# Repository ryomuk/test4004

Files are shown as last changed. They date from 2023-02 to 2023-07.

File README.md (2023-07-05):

# test4004
Test system for Intel MCS-4 (4004)  micro computer set

This document is written mostly in Japanese.
If necessary, please use a translation service such as DeepL (I recommend this) or Google.

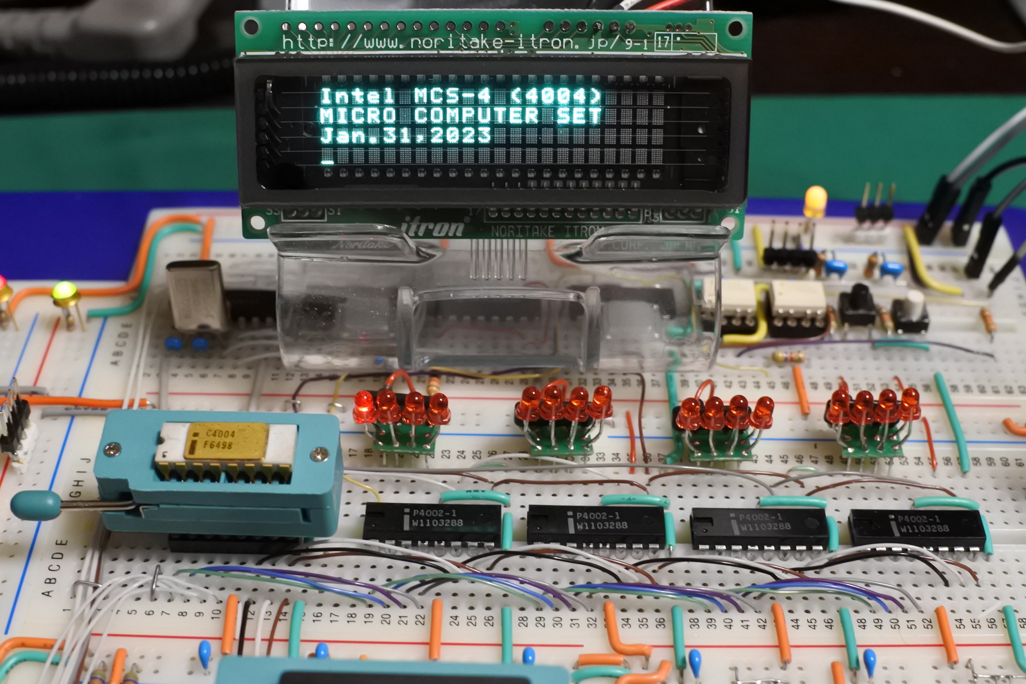
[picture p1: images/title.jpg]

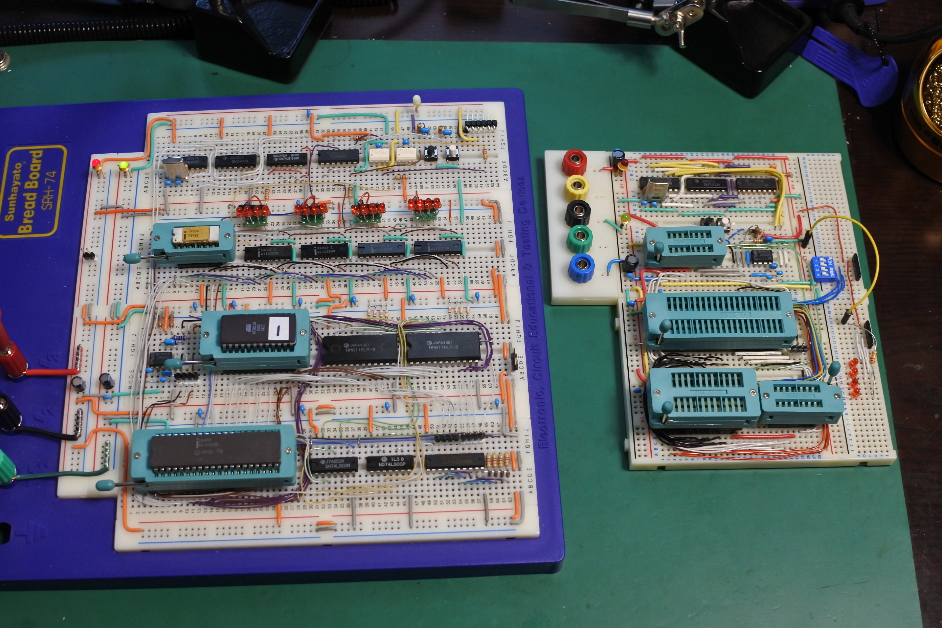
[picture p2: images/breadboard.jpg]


## 概要
昨年，運良くIntel 4004を入手することができました．せっかくだから動かしてみようと思い，このプロジェクトを始めました．
このレポジトリ(test4004)は電卓を作ったところまでで完成．続きはメモリ関連のハードウェアの変更も伴うので別レポジトリ(https://github.com/ryomuk/VTL4004 )に移行します．

## これまでに作ったもの
- 4004実験用ボード
  - シリアル通信用インターフェース
  - 簡易モニター
  - 電卓
  - [VTLインタプリタ(VTL4004)](https://github.com/ryomuk/VTL4004)

## 実験用ボードの仕様
- CPU: Intel 4004
- Clock: 740kHz
- DATA RAM: 4002-1(320bit) x 4
- Program Memory
  - ROM: AT28C64B (8k x 8bit EEPROM)
    - 000H〜EFFHの3.75KB利用可能
  - RAM: HM6268(4k x 4bit SRAM)x 2個
    - F00H〜FFDHの254byte x 16バンク, 合計約4KB
- 通信ポート: 9600bps Software Serial UART (TTL level)

## ToDO
- VTL的な言語
  - マンデルブロ集合を表示するぐらいのプログラムを実行させたい
  - →作りました．( https://github.com/ryomuk/VTL4004 )
- プリント基板作成
  - →作りました．( https://github.com/ryomuk/emu8080on4004 )

## 動画
Youtubeで関連動画を公開しています．
- https://www.youtube.com/@ryomukai/videos

## ブログ
関連する情報が書いてあるかも．
- https://blog.goo.ne.jp/tk-80

## 参考にした文献，サイト
### 4004関連開発事例
- [Intel 4004  50th Anniversary Project](https://www.4004.com/)
  - https://www.4004.com/busicom-replica.html
  - http://www.4004.com/2009/Busicom-141PF-Calculator_asm_rel-1-0-1.txt
- https://github.com/jim11662418/4004-SBC
- https://www.cpushack.com/mcs-4-test-boards-for-sale
- https://github.com/novi/4004MainBoard

### データシート
- http://www.bitsavers.org/components/intel/
- https://www.intel-vintage.info/intelmcs.htm

### 開発環境
- [The Macroassembler AS](http://john.ccac.rwth-aachen.de:8000/as/)
- [Intel 4004 emulator assembler disassembler](http://e4004.szyc.org/)

## 更新履歴
- 2023/2/20: ハードウェアをrev.0.2に更新
  - プログラム領域のメモリ(6116)のA8〜A10を4002のポートに接続してバンク切り替えで256byte(正確には254byte) x 8 バンク使えるようにした．
  -  これに伴い，バンク窓以外の空間をROM用に使う余地がある．
  - モニタプログラムにバンク切り替え命令('B')を追加．
  - rev.0.1は，「CM0とCM1に4002-1を2づつ」という構成でしたが，「CM0に4002-1を2つと4002-2を2つ」という構成も可能にしました．ピンヘッダでCMのラインを切り替えます．
- 2023/2/21: PM_READ_P0_P2 を PM_READ_P0_P1 に変更．
- 2023/2/23: 上記にバグがあったので修正．CTOI_P1_R5をCTOI_P1に変更．
- 2023/2/24: ハードウェアをrev.1.0に更新
  - プログラム領域のROMを2716から28C64B(2764等も可)に変更．
    - 000H〜7FFHだったROM領域を000H〜EFFHに拡大
  - プログラム領域のRAMを6116から6268(たぶん6168でも可)に変更
    - 254byte x 16 バンク使えるようにした．
  - 通信ポートをRAM3に，PMのRAMバンク指定用のポートをRAM0に変更
- 2023/3/12:
  - RAM2, RAM3を4002-1から4002-2に変更
    - RAM2, RAM3のバンク(CMRAM)の設定を1から0に変更
  - CR，LFが入力されたときの挙動の変更．(CRを無視していたのをCR or LFでの入力にした．)
- 2023/4/14: 0100H前後のメモリが重複してSQRTの計算時に暴走してしまっていたので修正
- 2023/7/5: 回路図で6268のピン番号の一部に誤りがあったので修正．(rev1.0→1.01)

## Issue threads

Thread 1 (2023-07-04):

1.0 "Calc" code and Schematic?

slobdir, 2023-07-04:
This was a very interesting project. I wire wrapped something like your Version 1.0 board and I found a few errors in the 1.0 schematic around the 6268. the I/O's should be 1-4: 15,14,13,12 and the /WE_OPx should be pin 11. Are these the only issues?

Also, I could not get SQR or D to work in the CALC.ASM code. Was there an update to the code, this may have been mentioned in your blog? Thanks!

ryomuk, 2023-07-05:
Thanks for your interest and the error report.
I have corrected the schematic and updated to rev.1.01.
As for the CALC.ASM, previously I found a bug and uploaded the fixed version on Apr.14. I recompiled it and run on the board. It works fine and I found no errors.
I am using 4002-2 (not 4002-1) for RAM2 and RAM3, but it should not matter.

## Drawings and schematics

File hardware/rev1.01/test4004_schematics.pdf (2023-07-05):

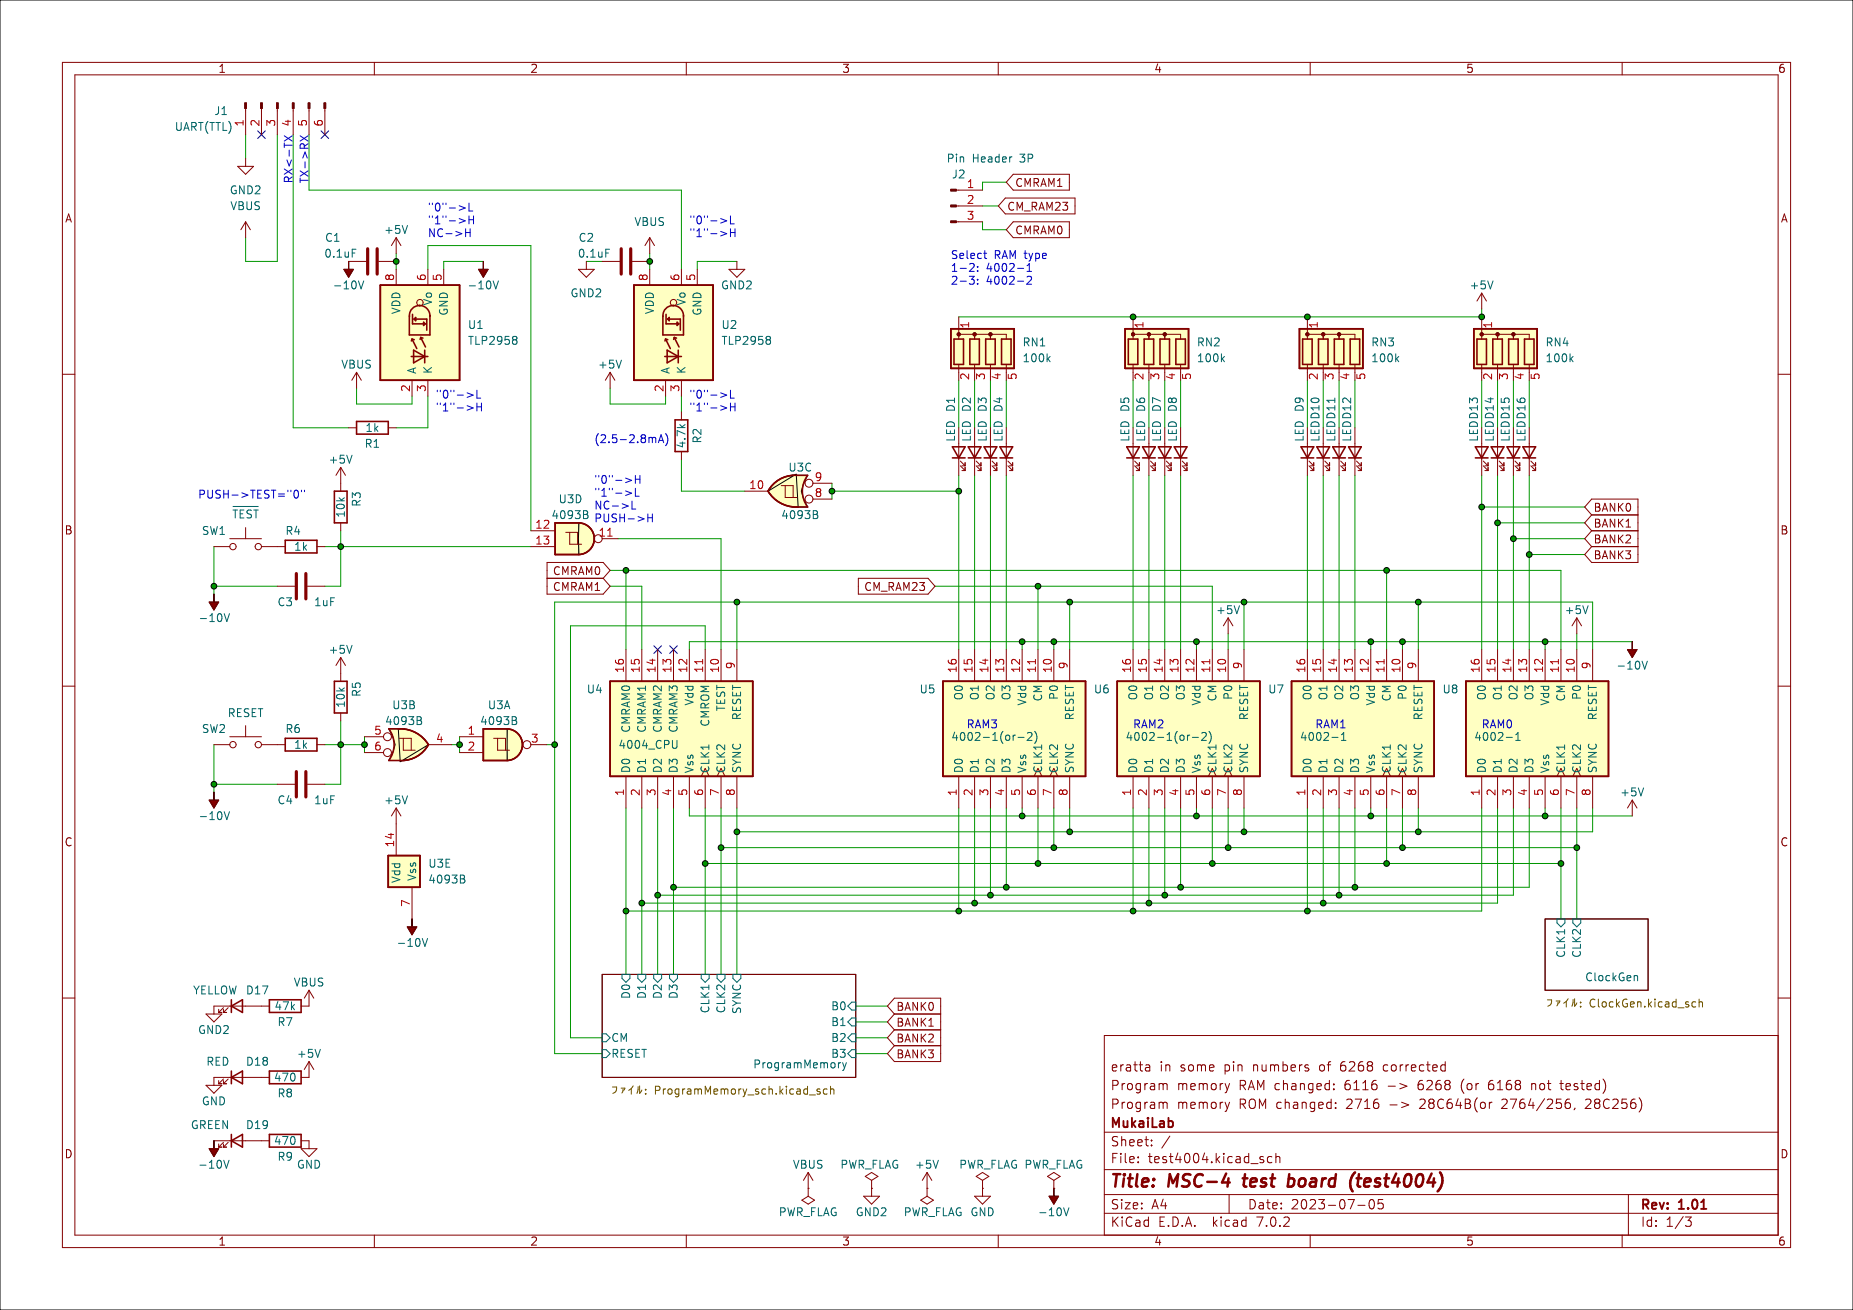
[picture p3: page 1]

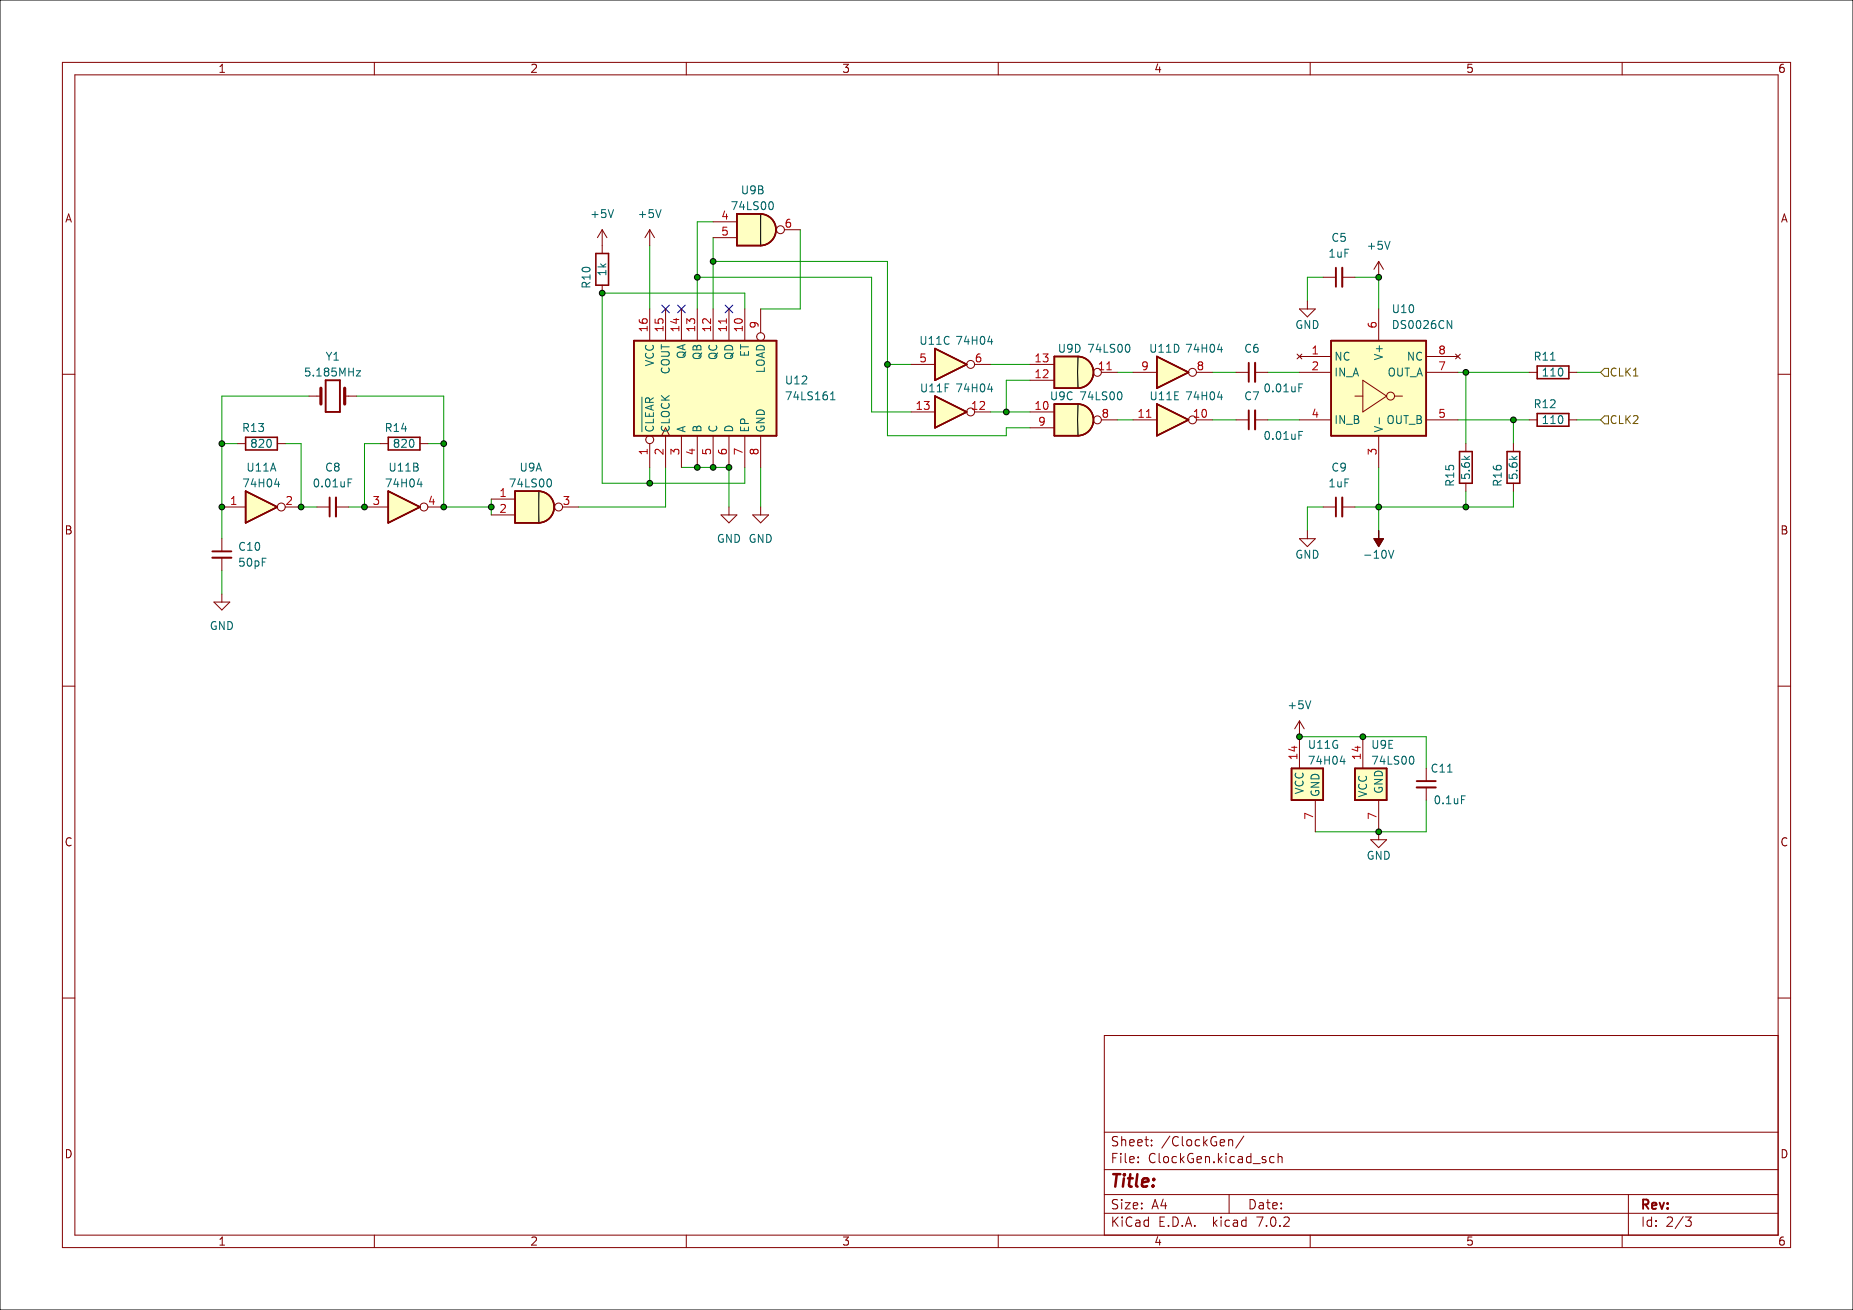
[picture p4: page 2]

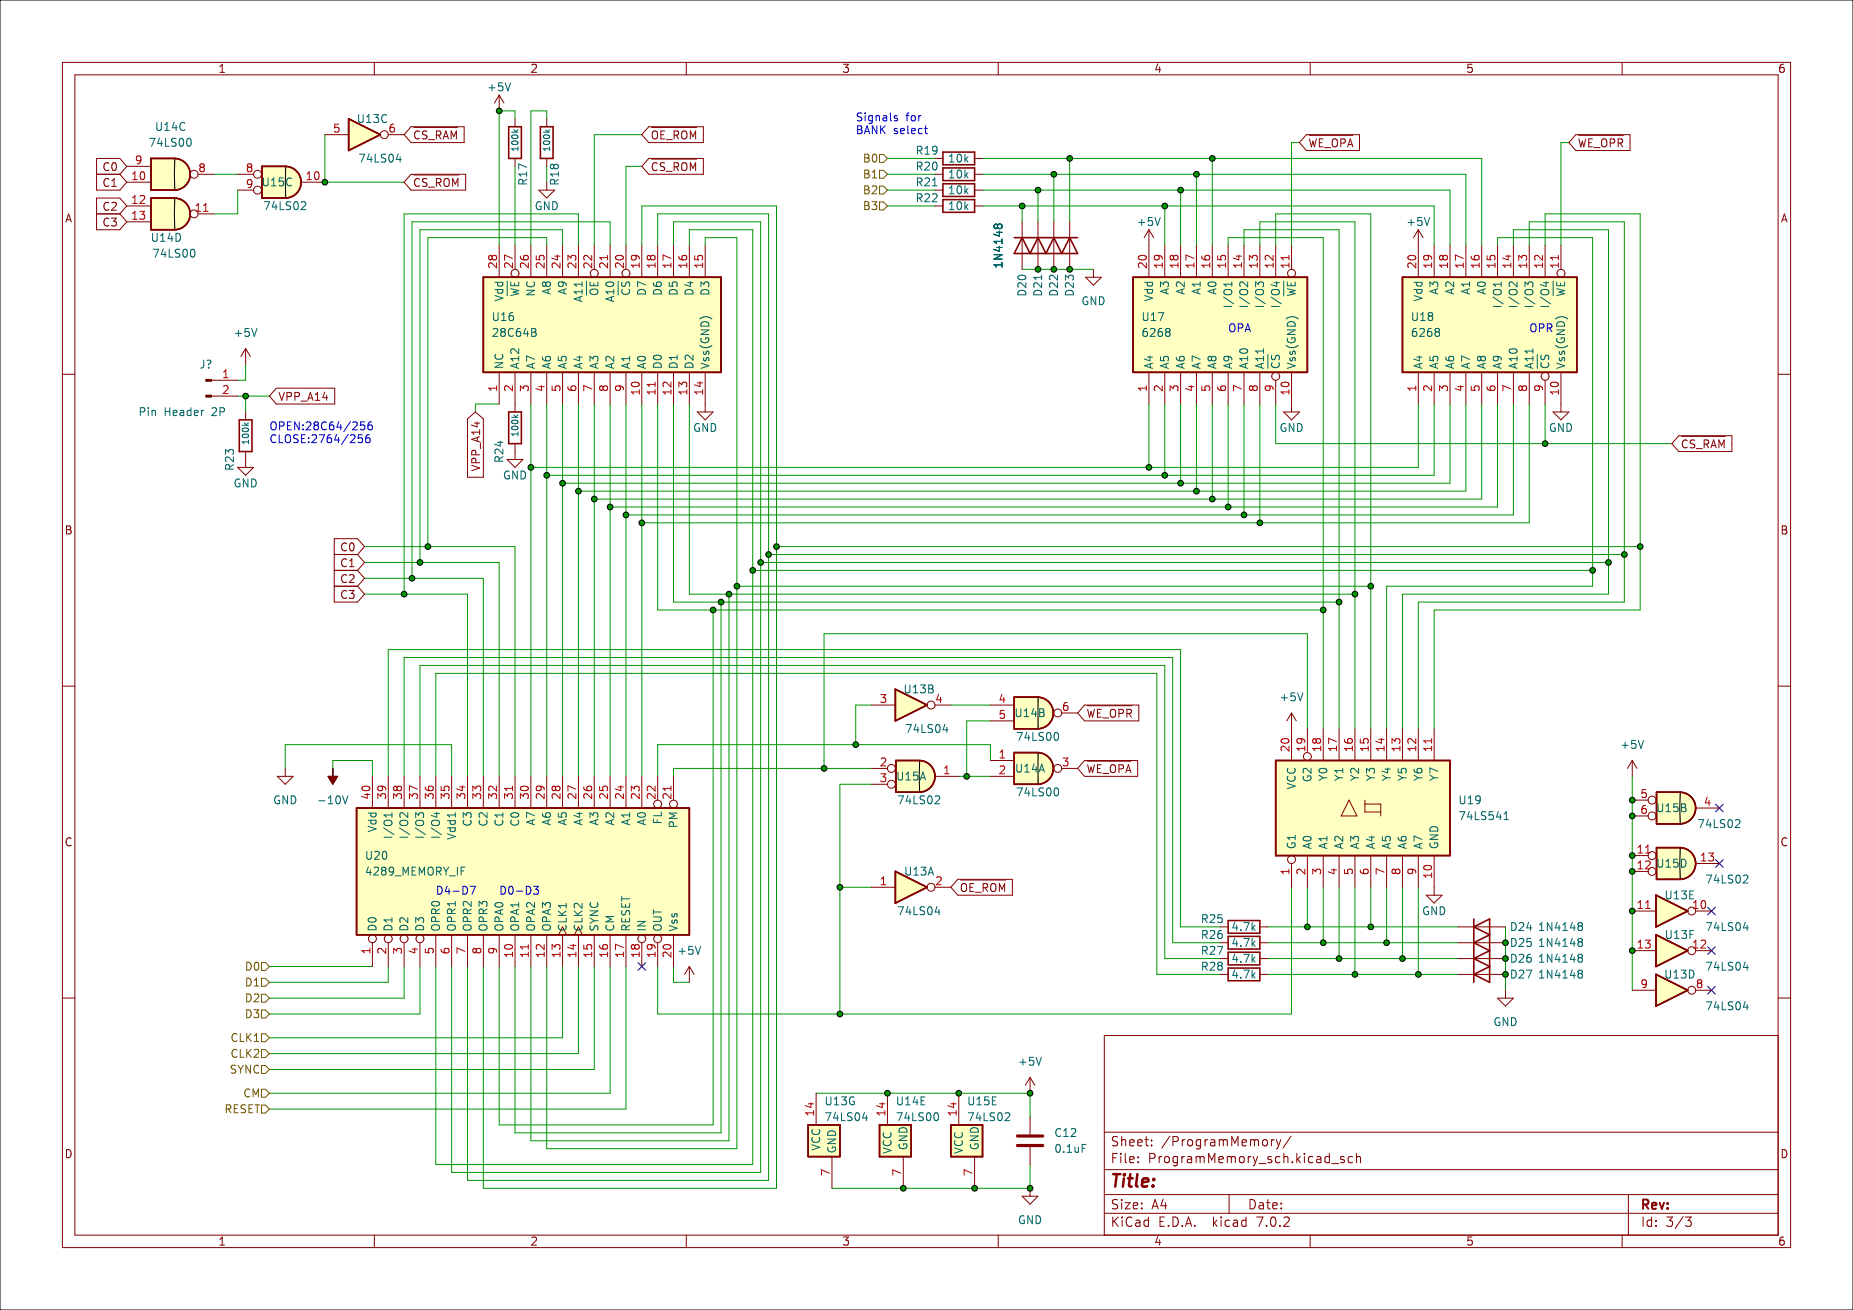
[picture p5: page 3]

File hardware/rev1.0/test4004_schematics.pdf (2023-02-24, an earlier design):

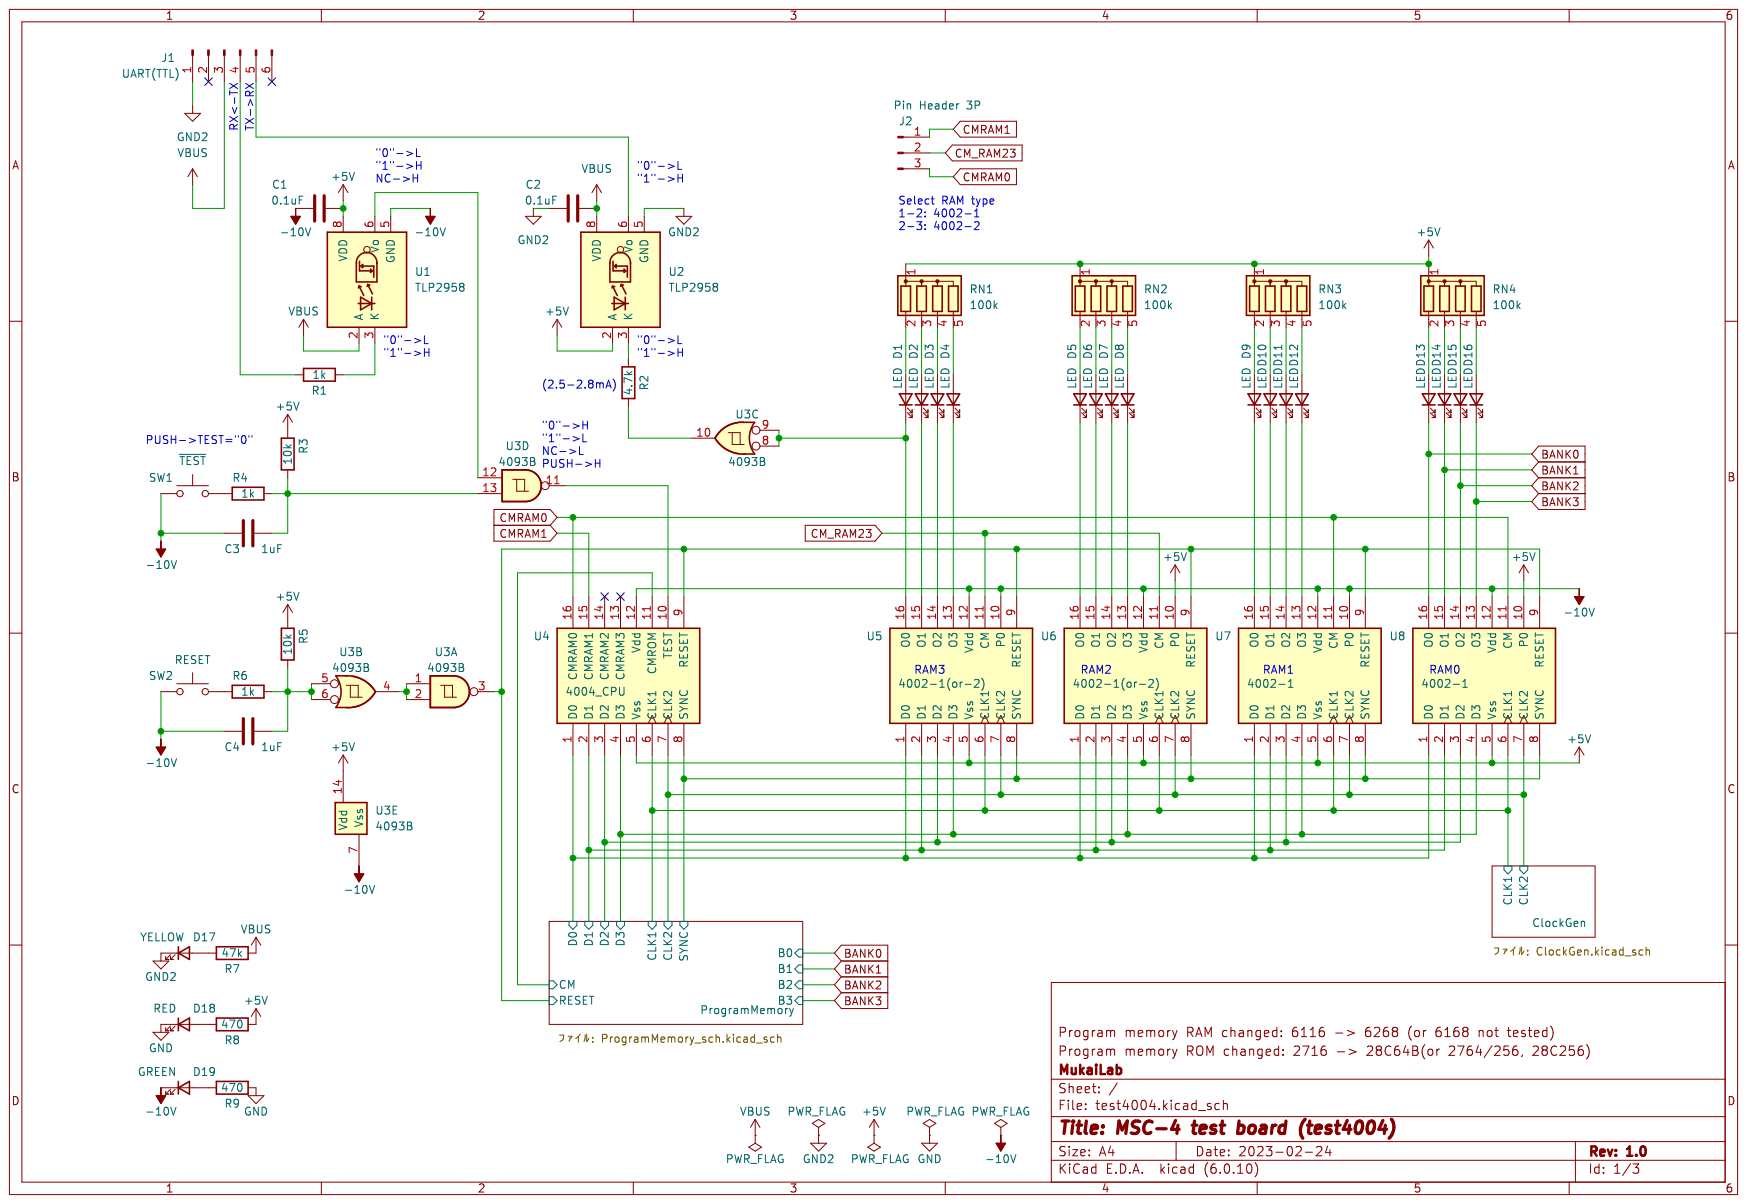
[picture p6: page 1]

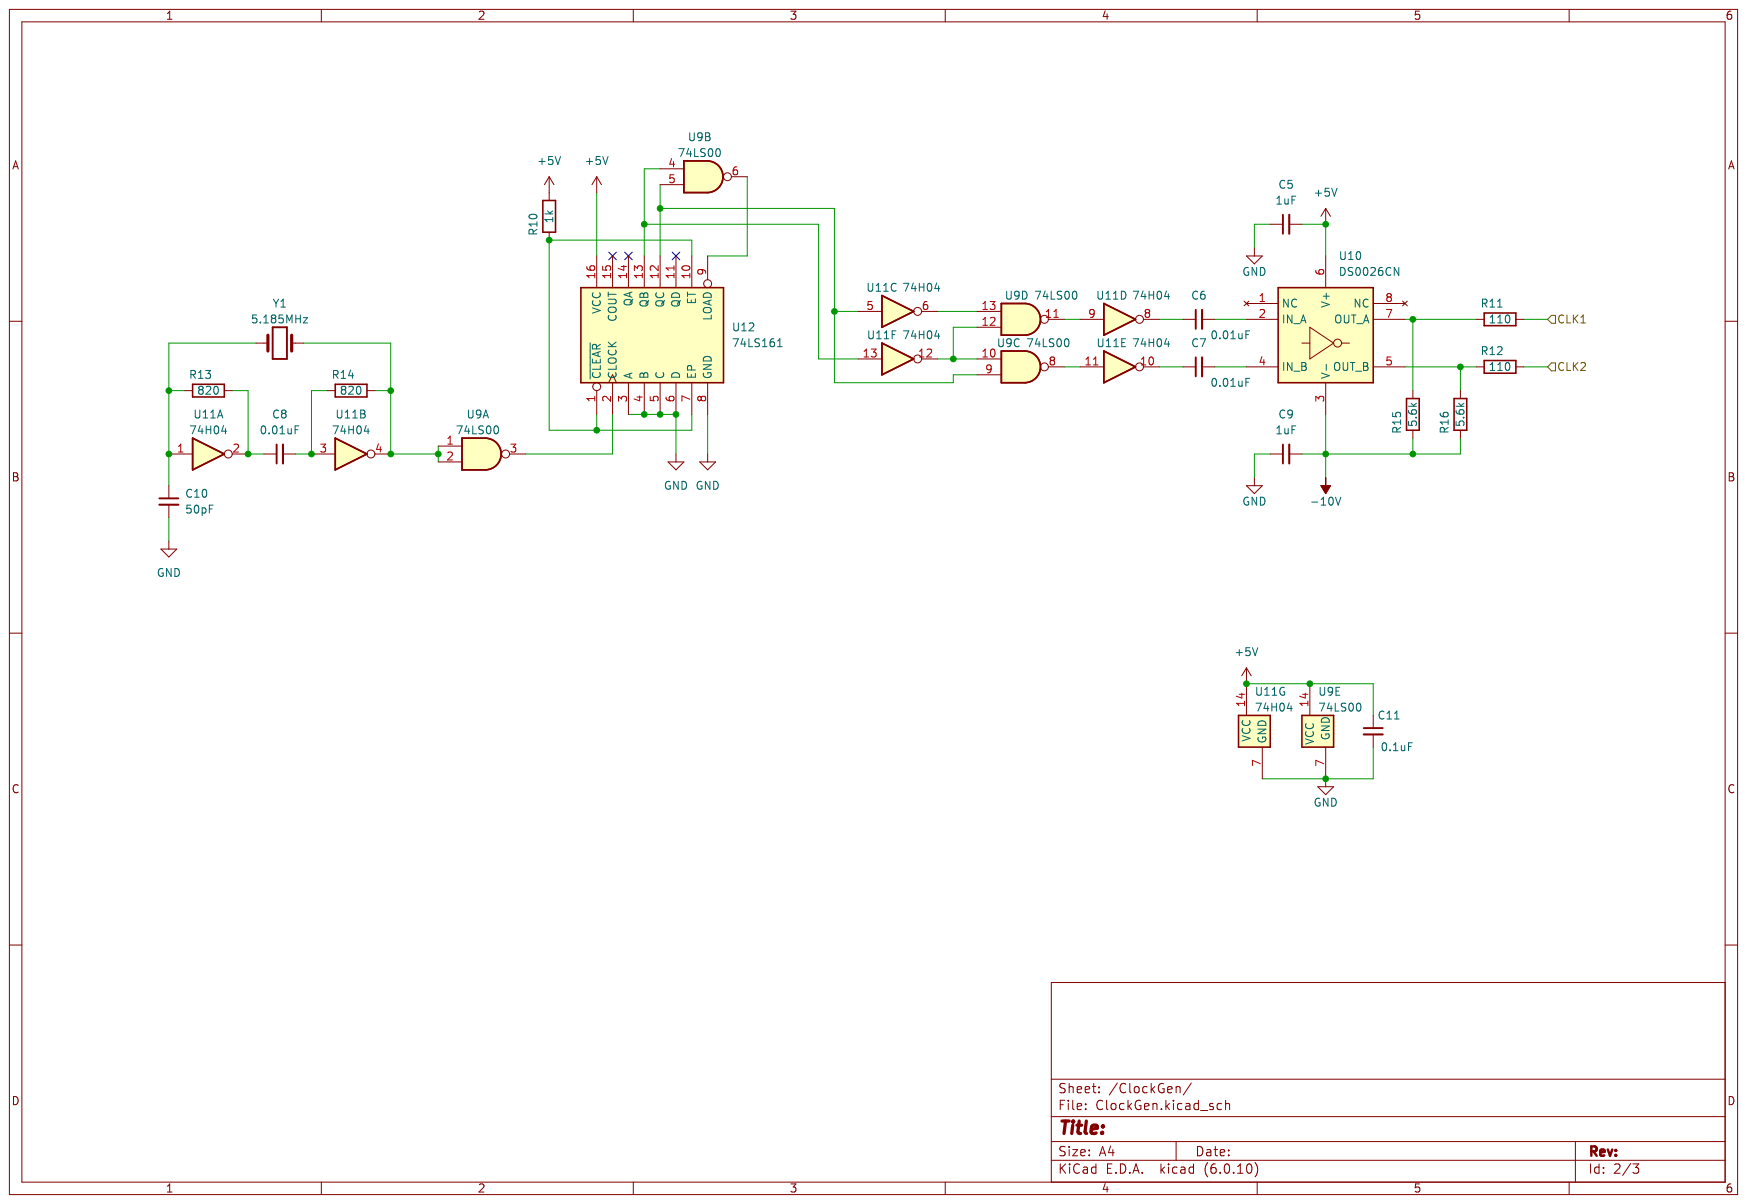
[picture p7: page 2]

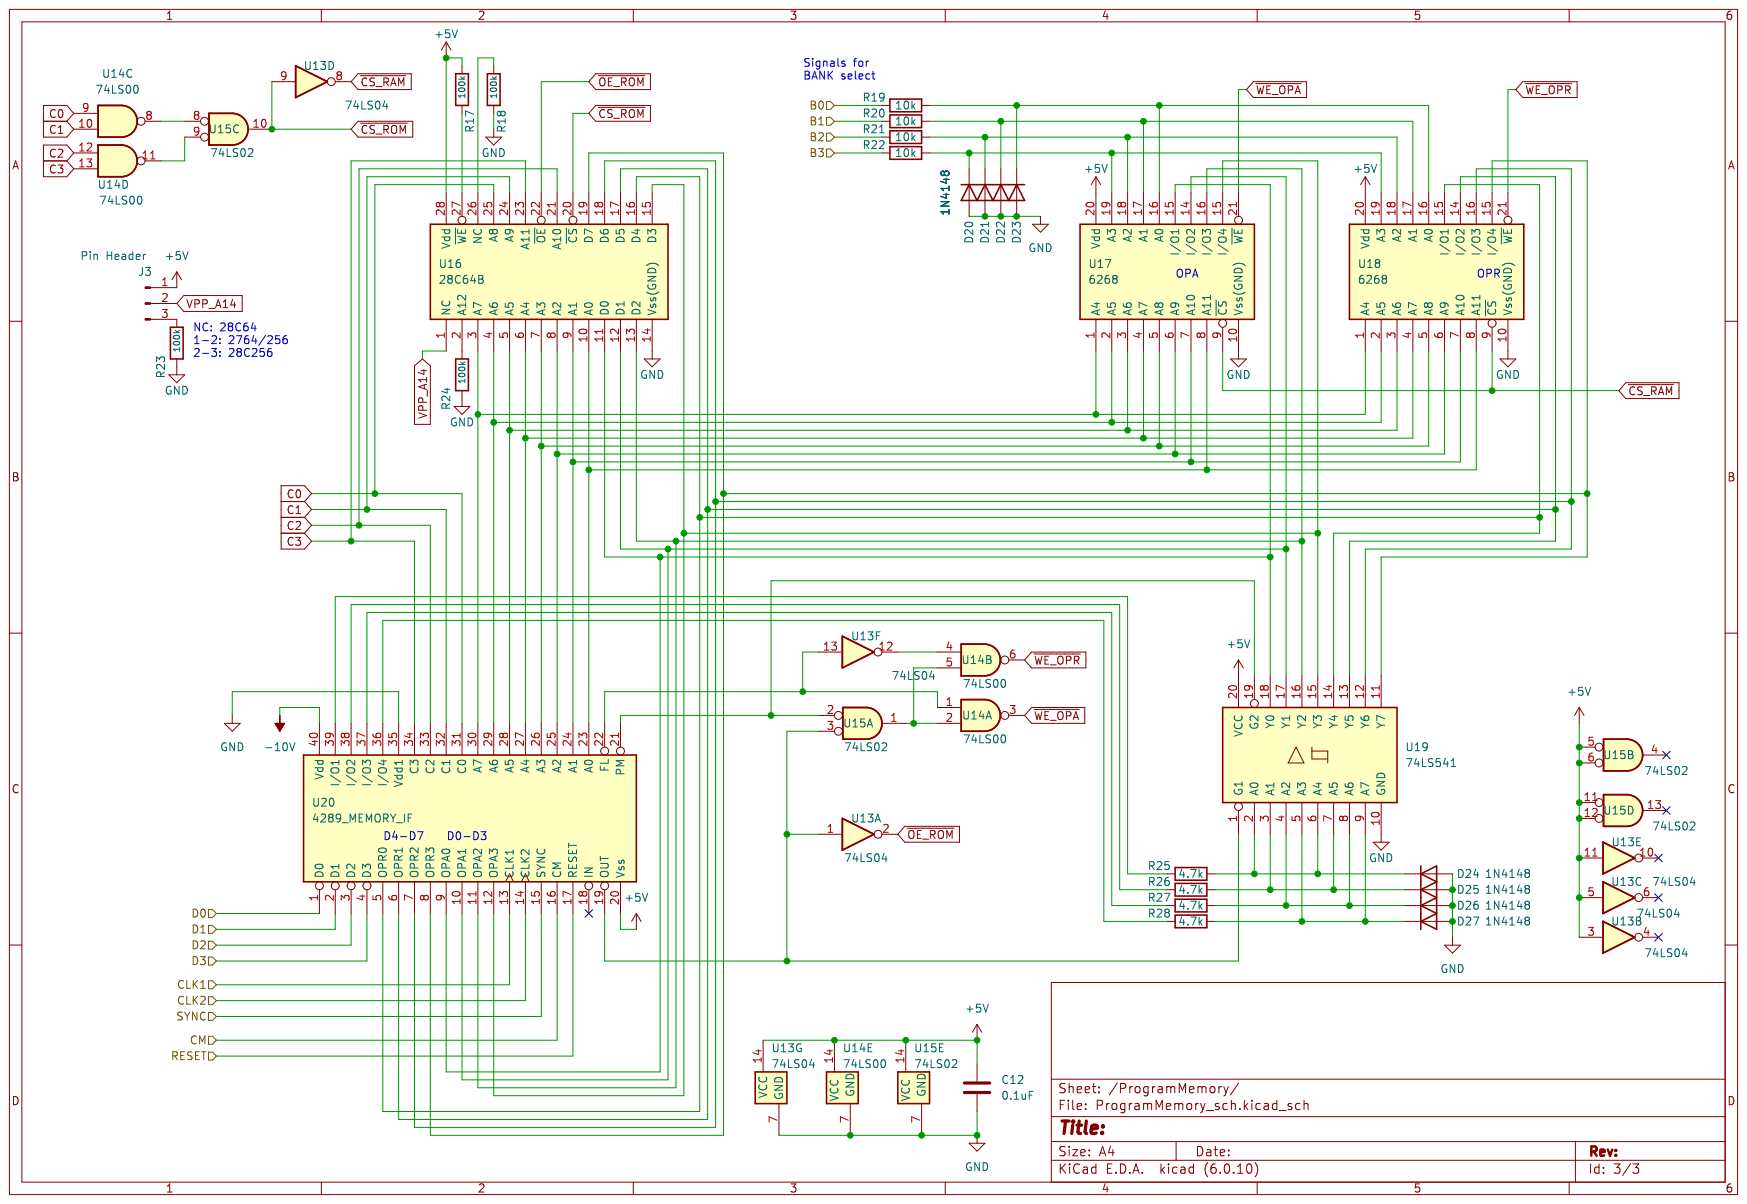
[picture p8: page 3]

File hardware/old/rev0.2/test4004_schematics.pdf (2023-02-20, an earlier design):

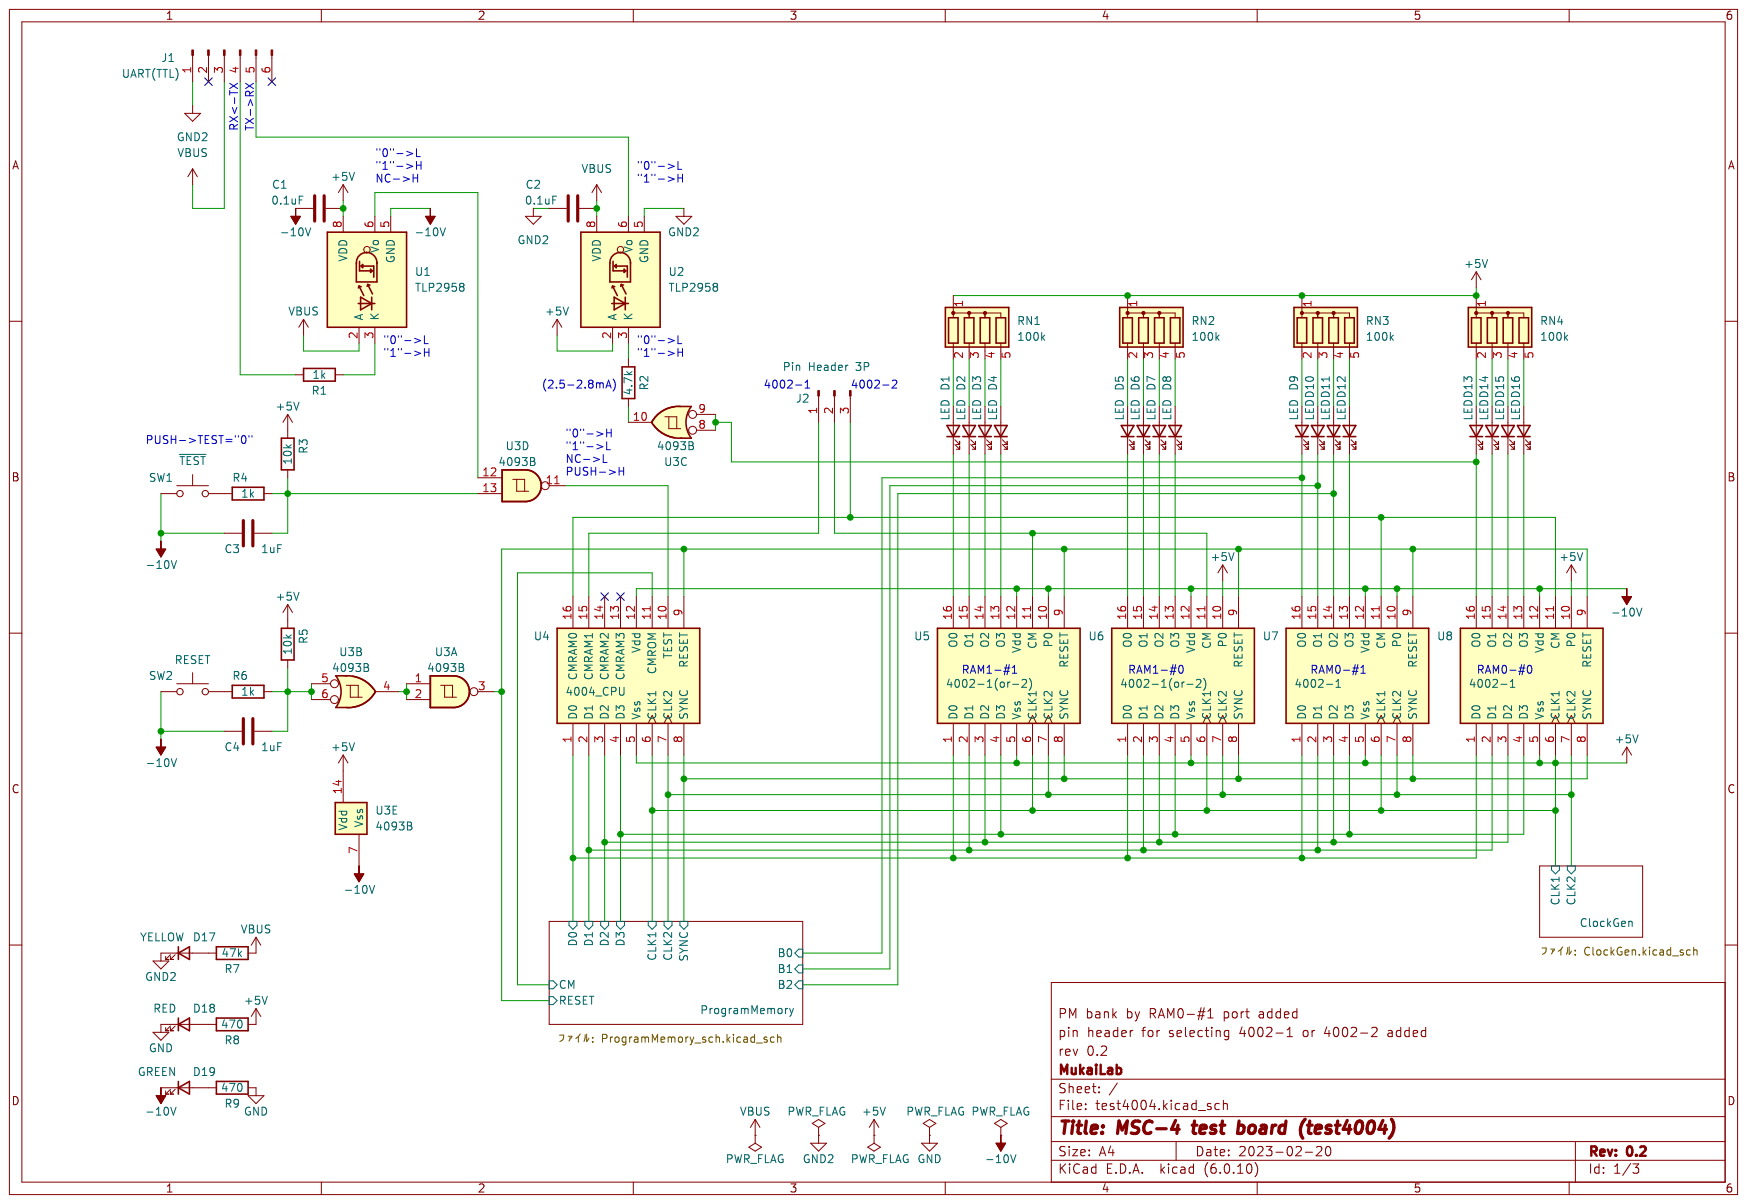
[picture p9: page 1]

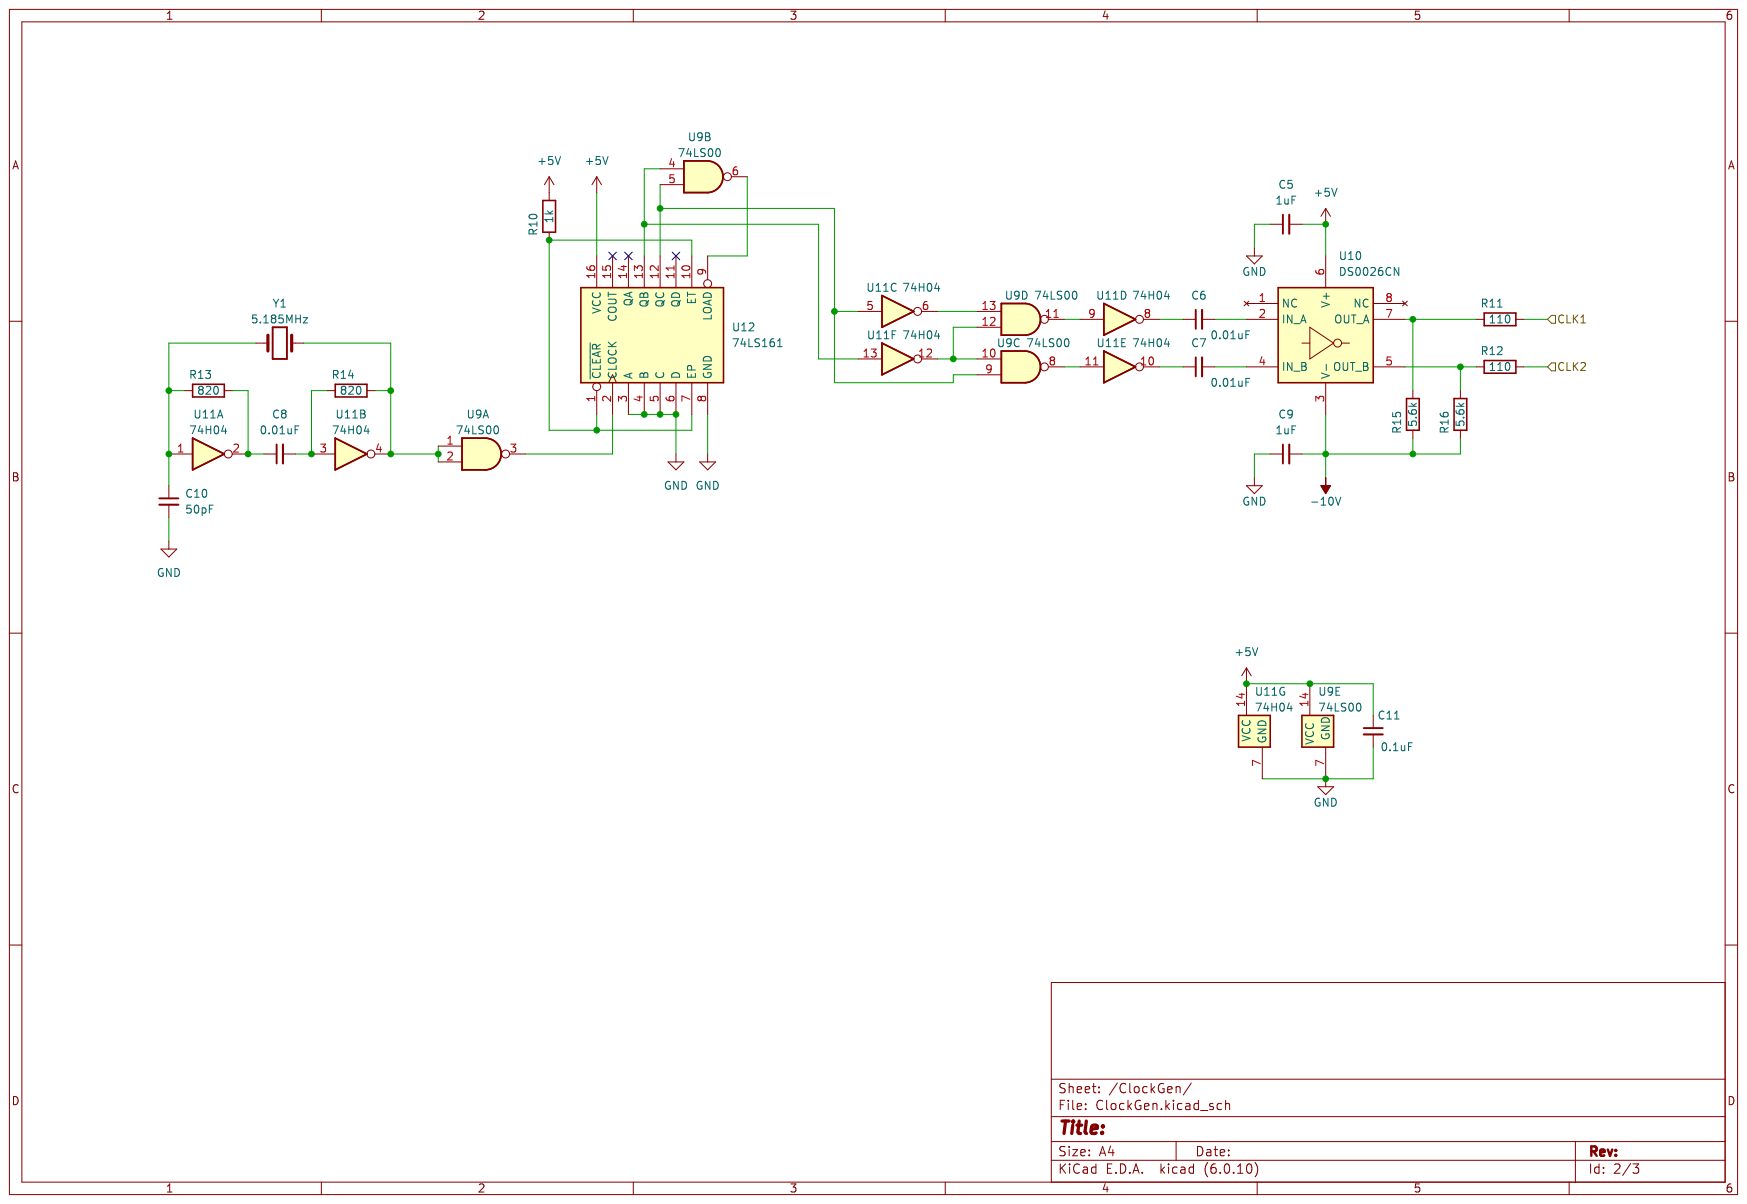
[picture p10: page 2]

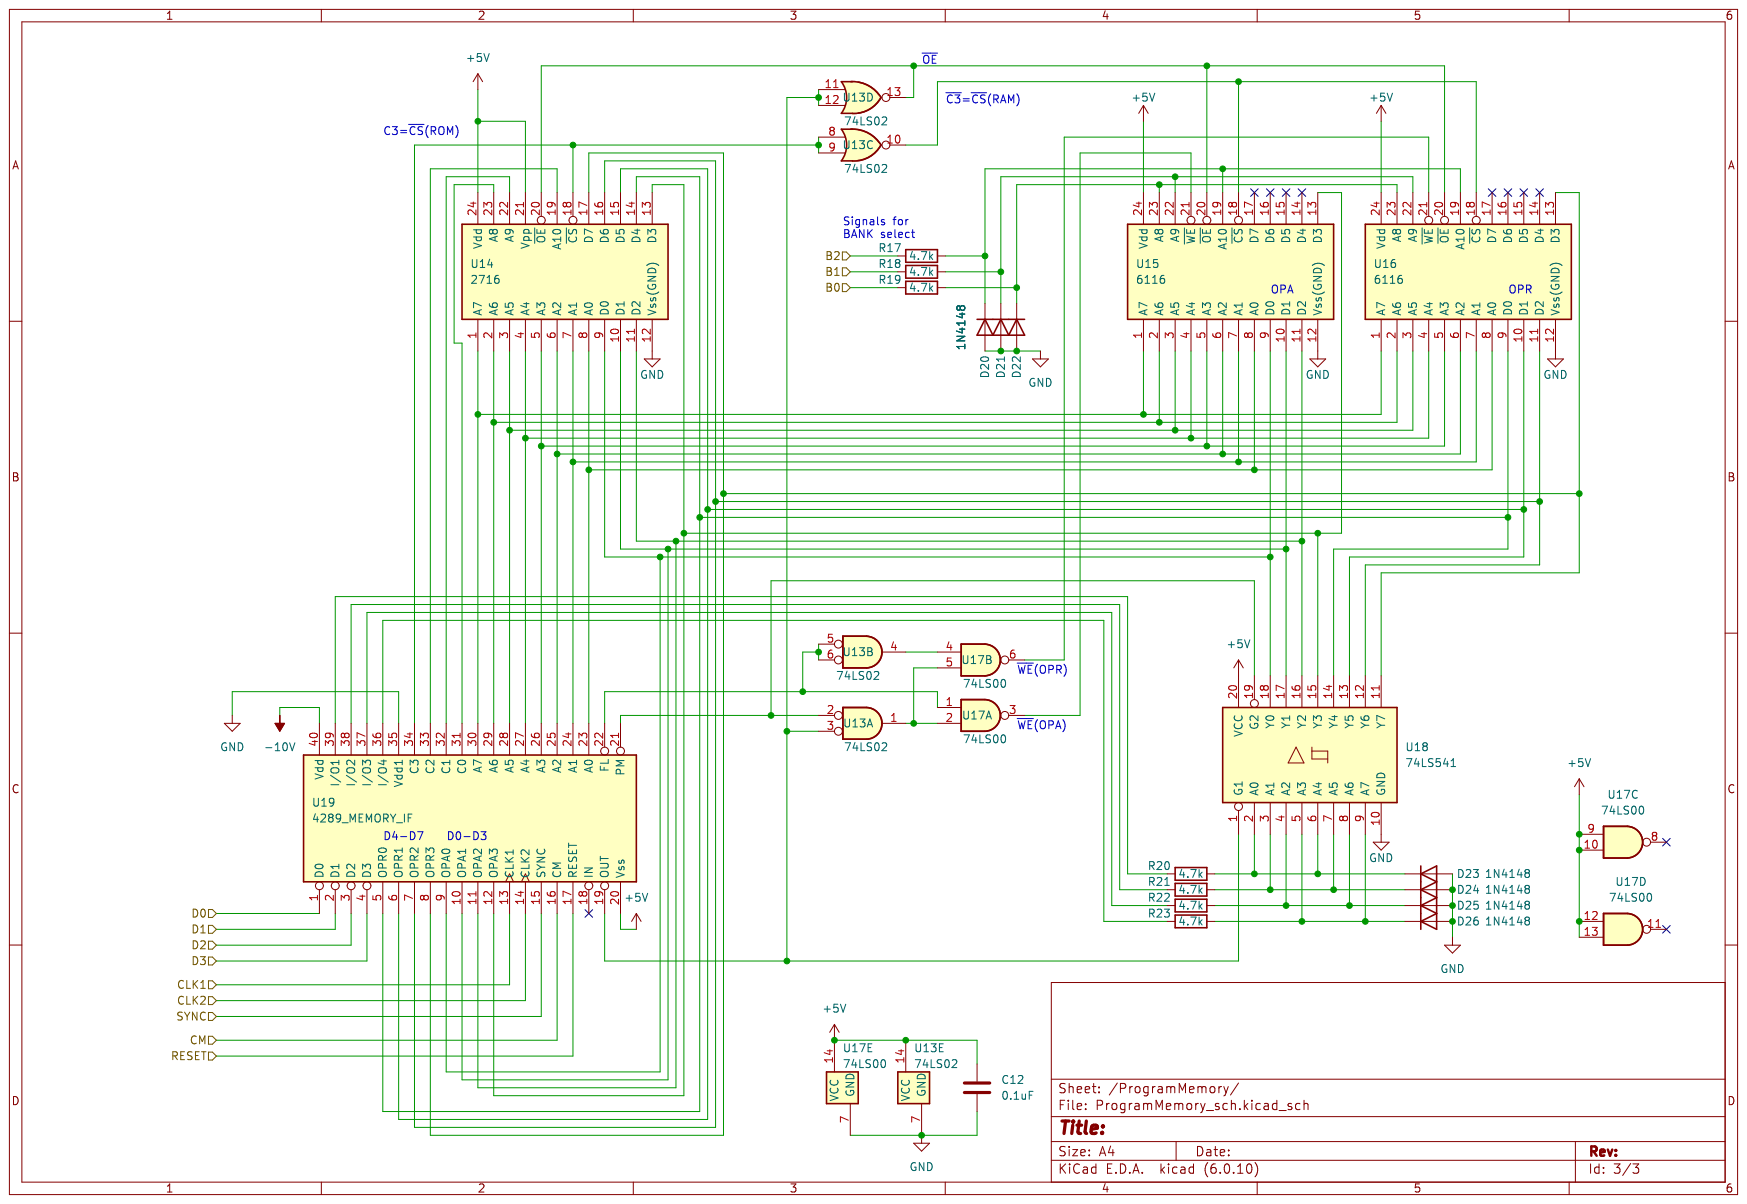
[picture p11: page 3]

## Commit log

2023-02-20 PM bank implemented
    [ClockGen.kicad_sch, ProgramMemory_sch.kicad_sch, test4004.kicad_pcb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]
2023-02-24 memory system updated
    [ClockGen.kicad_sch, ProgramMemory_sch.kicad_sch, test4004.kicad_pcb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]
2023-07-05 pin numbers of 6268 corrected
    [ClockGen.kicad_sch, ProgramMemory_sch.kicad_sch, test4004.kicad_pcb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]
